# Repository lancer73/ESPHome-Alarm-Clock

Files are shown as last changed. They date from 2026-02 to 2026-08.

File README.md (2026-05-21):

# ESPHome-Alarm-Clock
Alarm clock built in ESPhome with the following features:
- MAX7219 matrix display
- User configurable display behavior for light level and on/off
- One alarm per weekday
- Sensors to let Home Assistant handle the "waking up"
- Automatic fallback to piezo buzzer
- Sensors for automations before and after the alarm time
- Alarm can be triggered from HA for normal and emergency situations
- Switchable led from HA to convey a message or reminder
- Banner message functionality
- Can work without wifi/home assistant. Most important settings are accessible from the alarm clock itself.
- Can be used as a bluetooth proxy for tracking BLE beacons

There are two different versions of the alarm clock. A full version with additional leds and environmental sensors and a light version. 3D print designs are included for both. The normal version has buttons at the top and sensors in the back, the light version has buttons on the front and a ligh sensor on the top.
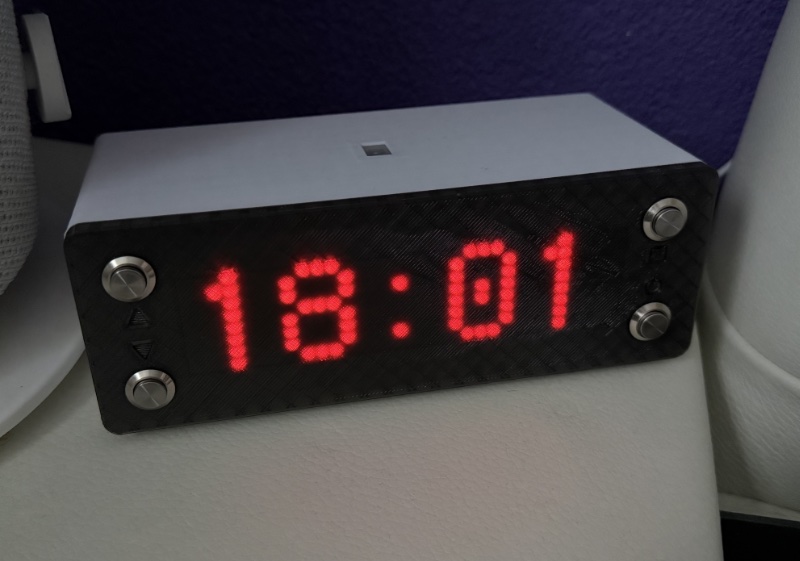
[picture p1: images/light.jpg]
|  | |
|---|---|

## Parts list
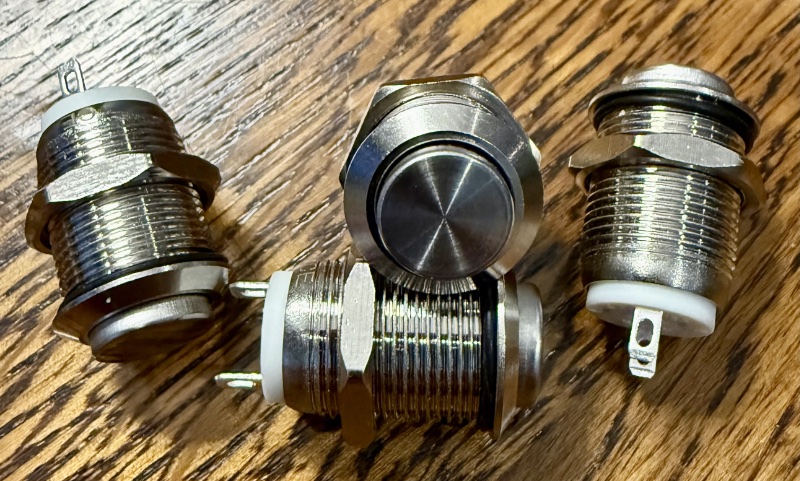
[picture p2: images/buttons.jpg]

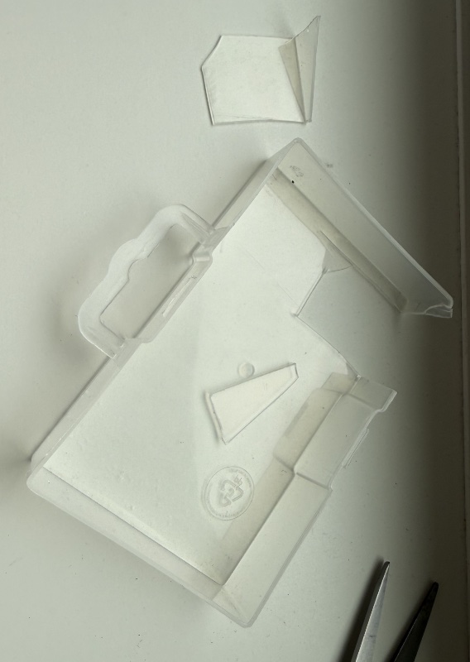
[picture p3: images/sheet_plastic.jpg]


With these parts you can build the "light" version.
- Transparent black filament for 3D print of front
- Colored filament for housing
- Piece of sheet plastic for illumination sensor window (see picture)
- 4x pushbutton (see picture)
- 5x 2k2 resistor
- KY-12 Piezo buzzer
- BH1750 Illumination sensor
- MAX7219 4x8x8 matrix display
- DS1307 real-time clock
- ESP32 DevkitC v4 controller or another ESP controller with enough addressable pins, SPI and I2C bus and an analog-digital converter.
- A piece of electrical tape to cover the led on the controller board (unless you want a "shine in the dark" alarmclock.
- USB cable with USB-A and USB-micro connector
- USB charger

For the full version you need these parts as well:
- CCS811 Gas sensor (TVOC/eCO2 monitoring)
- BMP180 Temperature sensor (for more accurate TVOC metering)
- 3x led in various colors
- 3x resistor in 220 to 600 ohm range (depending on max wanted brightness)

## 3D print
The print files are included in the repository. The normal version comes in three parts, the ligh version in two. I was able to print all parts without supports on a Creality K1C printer. The normal version in the picture was printer with supports, hence the lines below two of the buttons. Print the bodies standing on their backsides.

The other parts can be printed in any color or material. Be aware that if your print in a light color, the led of the controller will shine through. Do not forget to tape off the led.

All parts contain recesses to house the various parts, except for the controller itself. I leave the controller "free floating" in the housing to not push to much stress on the cabling. 

## Assembly
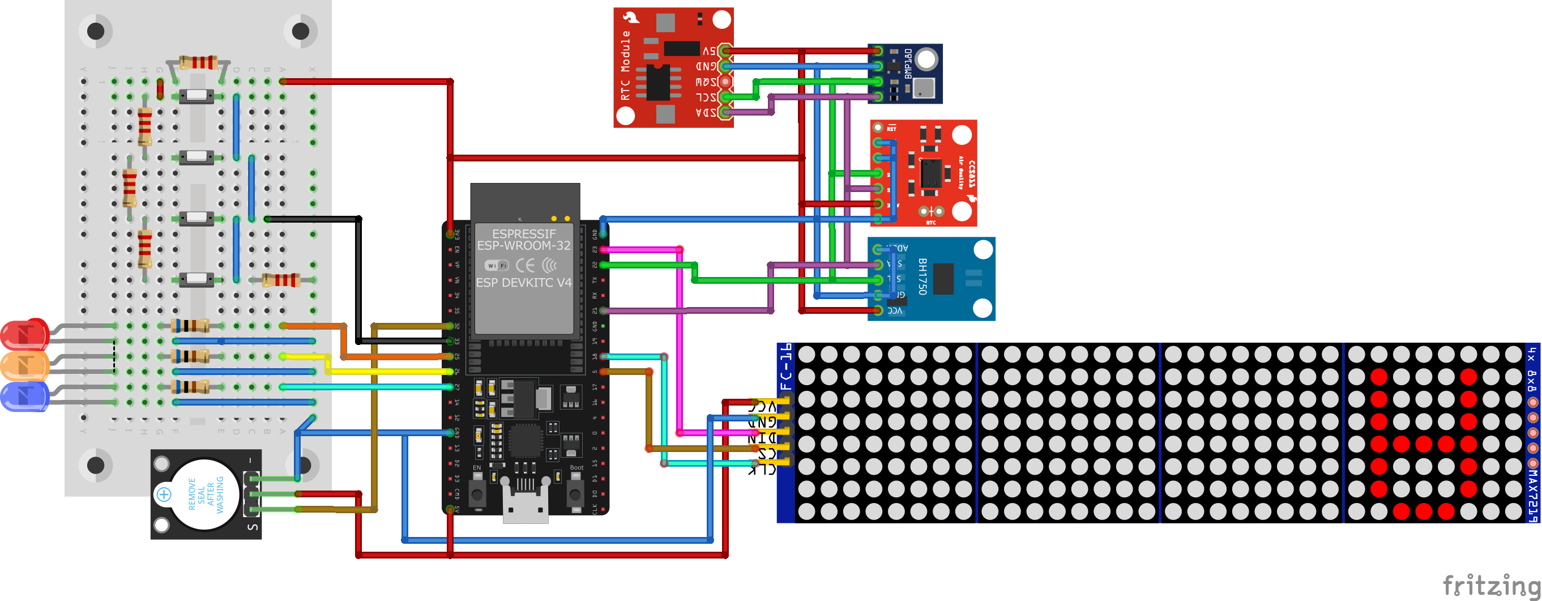
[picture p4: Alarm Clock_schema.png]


The picture above shows the wiring of the alarm clock. Most of it is straightforward. All sensors use the same I2C bus. The led connections are straightforward as well, Use a resistor in the 220 to 600 ohm range, depending on the maximum brightness that is needed from the led. The leds are controlled via the ledc component of ESPhome. The illumination sensor will be used to set the brightness of the leds dynamically.

The buttons are connected in parallel. The resistance will determined by the button that has been pressed. This is measured by an ADC pin of the controller. With no buttons pressed the resistance is indefinite leading to a detected voltage of about 0V. Pressing the top button leads to a total resistant of 4k4 ohms, measured in between the resistors leading to about 1.6V. The lowest button has all 5 resistors in serial connection. The resistor on the red plus line is there to limit the voltage on the ADC pin.

### Pins used
| Pin | Purpose |
|:-----|:---|
| 3v3 | Buttons, BH1750, CCS811, BMP180, DS1307 |
| 5v  | MAX7219 display, KY-12 buzzer |
| GND | Everything leads to GND... |
| GPIO5 | CS connection of MAX7219 |
| GPIO18 | SPI CLK pin of MAX7219 |
| GPIO21 | SDA pin of I2C bus leading to BH1750, CCS811, BMP180, DS1307 |
| GPIO22 | SCL pin of I2C bus leading to BH1750, CCS811, BMP180, DS1307 |
| GPIO23 | SPI MOSI pin for MAX7219 |
| GPIO25 | Red led |
| GPIO26 | Amber led |
| GPIO27 | Blue led |
| GPIO32 | Piezo buzzer, controlled through ledc component to enable tunes & music |
| GPIO33 | Buttons |

### Putting it together
Personnally I like to do everything with Dupont connectors as most builds get taken apart eventually and the parts re-used. When the setup has been tested, the parts can be glued into place. Remeber to put the buttons in first before you solder them as they need to in through a hole. I used hot glue to put everything in place. 

The light alarm clock body has a large hole in the back allowing the micro USB connector to pass (the normal version has a slot). After the cable is in, put the cover in place and hot-glue it in.

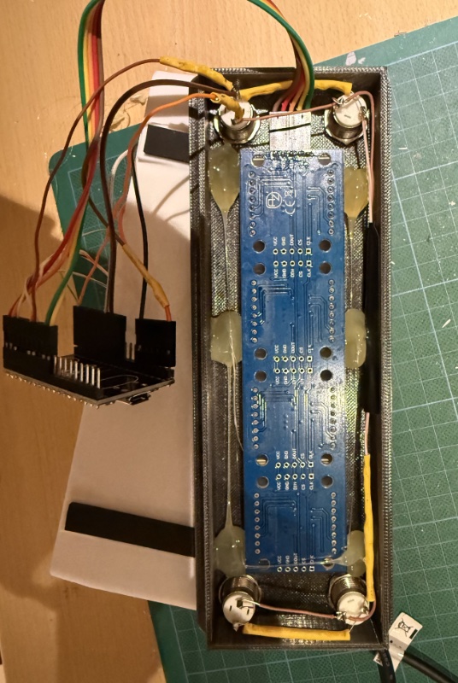
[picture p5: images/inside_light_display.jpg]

The picture on the left shows the MAX7219 display glued in place in the front panel (light version). Make sure the panel fits snugly and that is is completely flat. You will see in the front when it is not. The yellow heat shrink tubing covers the resistors. (this is actually the third one I built. Got tired of crimping on Dupont connectors).

6 dots of hot glue keep everything in place.
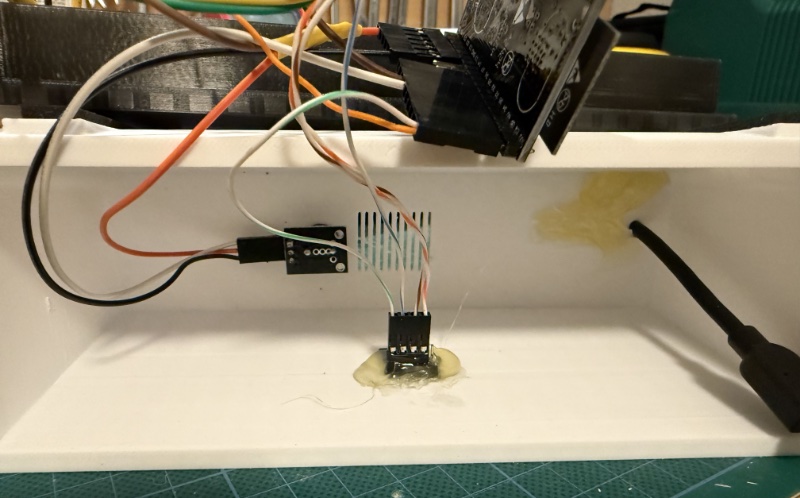
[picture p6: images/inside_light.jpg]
<figure>
Another picture showing the inside of the light version. BH1750 and KY12 are glued in place as is the inset in the connector entry hole in the back. Cut a piece of sheet plastic to size and put it in the recess first, before putting in the BH1750. I used some super glue to gluw the window into place first.

I use a piece of double-sided tape on the battery side to keep the DS1307 in place.

The front display will slide into the housing. It is a tight fit, but fit it does. No glue needed to secure it. The same goes for the back panel of the normal version.

With everything in place you can create the config in ESPHome. Copy the contents of alarm_clock.yaml and adapt where needed. 

Most relevant configurations:
| Substitution | Purpose |
|:---|:---|
| chip_orient and reverse_enable | this allows you to rotate the display if you mount it upside down, or just want to put the alarm clock in an upside down position (attach it to a shelf) |
| hide_button_sensor | change this to false so you can read out the voltage with each button. With these values change the display_min/max (button with the square), onoff_min/max (button with the circle), up_min/max and down_min/max values. Take at least 0.1V of margin above and below the detected value. Make sure button voltage settings do not overlap. |
| baseline | this is the baseline setting for the CCS811 sensor. When first powering up make sure there is an empty string here. Put the alarm clock in a well ventilated position for a few hours and then look at the controller logs to find the baseline of the sensor and copy that value in. |
| weekdays | You can change weekdays to your local language. This sunstitution is just the first 2 letters of all days in the week, starting at Sunday. |

*Do nor forget to set all the passwords and encryption keys in the configuration. Search for text between [] for everything you need to replace.*
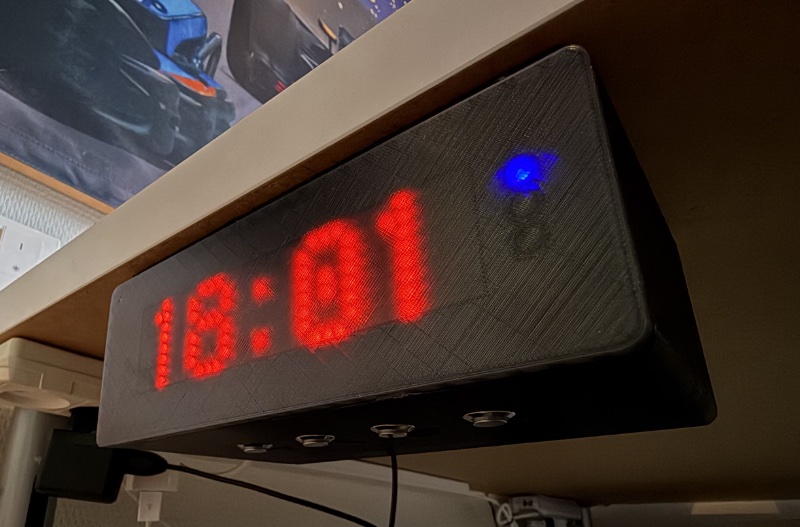
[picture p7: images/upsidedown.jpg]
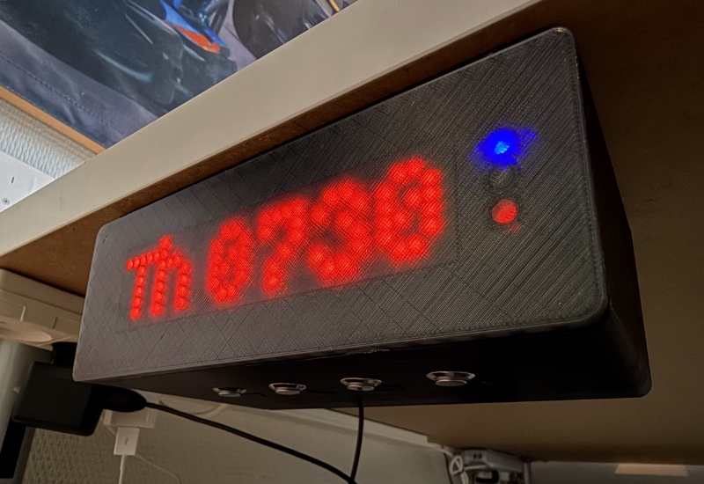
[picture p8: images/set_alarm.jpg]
|  |  |
|---|---|

## Manual
### Manual operation
#### The buttons
| Symbol | Name | Purpose |
|:---|:-----|:---|
| Square | Display | With the display button you can cycle through the pages. Pressing it once will lead to the message and environmental sensors, pressing it twice will lead to the alarm for the next day, pressing it again for the day after etc. If you have no environmental sensors and the message is empty (like after boot), the message is not displayed and the screen skips to the next. Pressing it 8 times will lead back to the time display. The display will revert back to time automatically  (30s timeout by default). If the display is off, this button will turn on the display first. Keep this button pressed to access clock settings. |
| Circle | On/Off | This button either toggles the display on or off when showing time or environment parameters or enable/disable the alarm time or settings shown in the display. By keeping it pressed you can set an alarm time once, meaning the alarm will be disabled for the next week automatically. The red led will show if an alarm is enabled and the amber led will show if it is enabled once. If you have no leds, the status will be shown using the right topmost pixel of the display (red) and the pixel below that (amber).
| Up | Up | When the time or environment parameters are shown, the up button will be forwarded to Home Assistant to control room lights or whatever you choose. When showing an alarm time, it will increase the alarm time by 5 minutes. If you keep the button pressed the time will be counting up in steps of 5 minutes. Up and down are also used to in- or decrease settings.
| Down | Down | Same effect as the up button, but decreasing in time |

#### The display
If an alarm is set within 24 hours the red led or right topmost pixel will light up.

It is possible to turn on the blue led or the right bottemmost pixel from Home Assistant to indicate there is a message. What the message is, is up to you. Could be a signal to put the trash out today, that your favourite GP driver has won in the night race or anything else. I use it to indicate if the alarm clock of a family member has been set.

The amber led will light up of the TVOC reading is above the warning threshold. If you have no leds, it will be the most right 3rd pixel from above.

If the display shows an alarm time, the amber led will indicate if an alarm has been enabled once.

#### When the alarm goes off
When the alarm goes off, the display will invert. Either Home Assistant will arrange the audible alarm e.g. by turning on a remotely controlled speaker, or you can use the built in buzzer. If the connection to Home Assistant has been severed the buzzer will sound anyway. You can use any button to snooze the alarm. The alarm will turn off by itself after 90 minutes by default.

#### When a message is shown
Press any button to dismiss the message. If the message is shown when the alarm goes off, the first press silences the alarm, the second press dismisses the message. I turn my alarm off without looking, that is why a second press is needed.

#### Setting the time manually
Normally the clock will take the time from the Internet. If the Internet is not available, or if you have disabled the wifi you can set the ime manually.

Keep the display button pressed until the network address shows, or "Wifi" crossed out. Press the display button again. The display now shows "St" with the current time. In- or decrease the time with the up/down buttons. The top right pixel or the red led will show up as soon as you change the time, indicating the time has be changed, but not set. The the proper time shows in the display, press "On/Off" to set the time. The time will be set at the press of the button.

Press the display button again to set the year in the "Sy" display. Also here the top right pixel or red led will show up as a sign that the day has changed. Set the configured day by pressing the "On/Off" button. The pixel/led will go out if you do. And the press display again for setting the dat in de "Sd" screen.

#### Other settings
If you press the "Display" button repeatedly you will cycle through the settings. The first setting is the wifi. If the Wifi is enabled and working, it will show an IP address. If the Wifi is off, it wil show "Wifi" crossed out. Toggle the Wifi with the on/off button. If you toggle of the wifi, you will also disable the BLE proxy.
| Code | Setting | Explanation |
|:-----|:---|:---|
| BLE | BLE proxy | The alarm clock can be used as a bluetooth proxy for Home Assistant BLE beacond tracking. Enable/disable by pressing "on/off" |
| St | Set time | Set the time and commit by pressing "on/off" |
| Sy | Set year | Set the current year and commit by pressing "on/off" |
| Sd | Set date | Set the day of the month and the month (ddmm) and commit by pressing "on/off" |
| On | Time to switch the display on | Time at which the display will be switched on automatically. Use the up and down buttons to change the time. The top right pixel or red led will show of the automatic display on/off has been enabled. Use the "On/Off" button to toggle the automatic display setting |
| Of | Time to switch the display off | Analogous to "On" |
| Dt | Display timeout | Number of seconds before the display automatically returns to the time display. When the display is in the off period it will also switch off after this time. The top right pixel or red led will show of the automatic display on/off has been enabled. Use the "On/Off" button to toggle the automatic display setting |
| Db | Display on before alarm | Number of minutes the display will switch on before a set alarm. The top right pixel or red led will show of the automatic display on/off has been enabled. Use the "On/Off" button to toggle the automatic display setting |
| Da | Display off after alarm | Number of minutes the display will switch off after a set alarm in a period when the display should be off. The top right pixel or red led will show of the automatic display on/off has been enabled. Use the "On/Off" button to toggle the automatic display setting |
| Df | Display font | Font for the main (time & message) display. Available are the normal font, a font that mimics a segment display and Star Wars' Aurebesh (2 variants) |
| At | Alarm timeout | Number of minutes after which the alarm should snooze automatically. The top right pixel or red led will show if the alarm buzzer is enabled. Use the "On/Off" button to toggle the buzzer setting. NOTE: If there is no connection to Home Assistant, the buzzer will always sound. |
| *  | Melody | Use up/down to select the wanted melody. Press on/off to play the melody. Melody choices are: Star Wars (Emprire strikes back), Mission Impossible, Mario Kart, Addams Family, Airwolf, James Bond, Swiebertje, Friends and Wake Me Up |
| Ab | Alarm buzzer | Select a random tune for the next alarm of use a single tune always. The top right pixel or red led will show if the alarm buzzer is enabled. Use the "On/Off" button to toggle the buzzer setting. NOTE: If there is no connection to Home Assistant, the buzzer will always sound. |

### Operation from Home Assistant or Web
Home Assistant and the web interface expose many more configurations and parameters. 
#### Alarms
There is an alarm time for every day of the week. The time is valid for that day only. There are two alarm switches for every day. The first will make the alarm go off on that day, the second, when enabled, will disable the alarm for that that after it has sounded. If you turn the once switch on, the alarm switch will be enables as well. If you switch off the alarm switch the once switch will be turned off as well.

There are shortcut buttons to turn off all alarms at once (starting a holiday) or enabling all weekday alarms (at the end of a holody).

#### Display on/off
It is possible to switch the display on and off using the physical buttons. This behavior can be tuned further. The thinking behind this is that some people are distubed hy the alarm display at night, either from the brightness, or because the can see the time. If you can't sleep, seeing the time doesn't necessarity help.

You can set a time at which the display should be turned off and a time when it should be turned on again. This is combined with the "Automatic display on/off" switch, which must be enabled for the set times to have any effect. If the display is off and the time is in the "off" window, the display and in/off buttons will turn on the display and automatically turn it off again after the timeout period.

The following configurations will also influence the display state:
| Setting | Effect |
|:---|:---|
| Display off after alarm | Keeps the display on for a number of minutes after the alarm has been snoozed. (Only valid in the "off window") The display will turned off after set minutes to not disturb other occupants in the bed |
| Display on before alarm | Turns the display on set minutes before the alarm sounds. Useful if you typically wake up before the alarm time. If the display is still of you can close your eyes again, if it is on it might be best to disable the alarm and get up |

#### Other sensors and settings
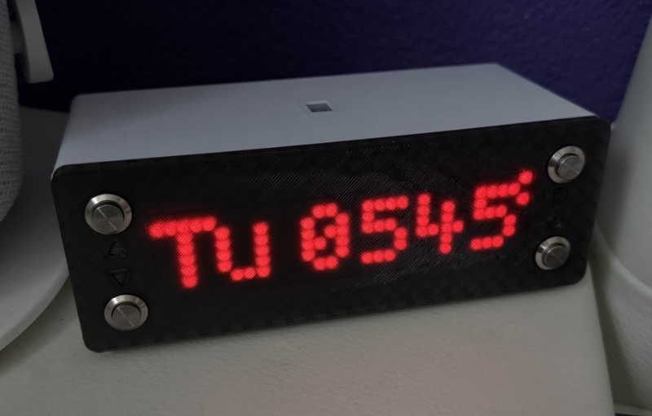
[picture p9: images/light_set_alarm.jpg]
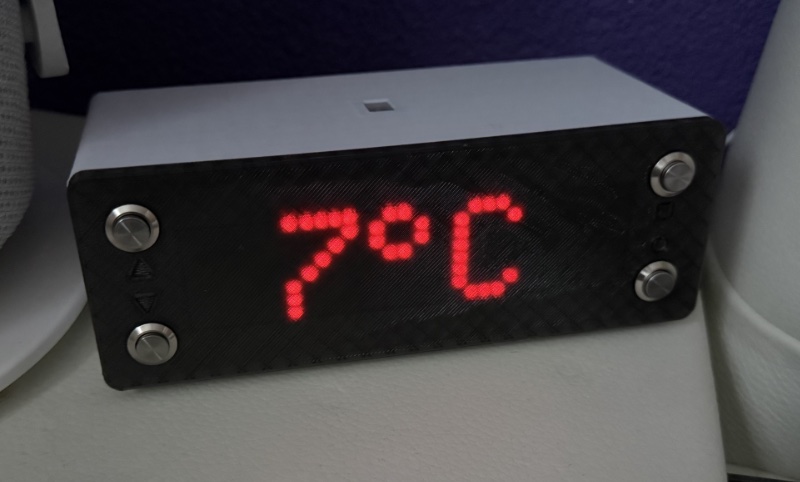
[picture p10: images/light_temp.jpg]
|  |  |
|---|---|
  
| Sensor | Meaning |
|:---|:---|
| Illuminance | Illuminance measured by the sensor. May be used for automatic control of lights for instance. |
| Left button | Binary sensor indicating the state of the down button. This way the press of a button on the alarm clock can turn on the lights. |
| Right button | Binary sensor indicating the state of the up button |
| After last alarm | Number of minutes after the last alarm went off. For automations that need to be kicked off after the alarm time, such as pre-heating the car |
| Alarm countdown | Number of minutes before the alarm. For automations that need to be kicked off before the alarm, such as turning on th ecoffee maker or setting the heating in the bathroom |

| Switch | Meaning |
|:---|:---|
| Alarm | Will turn on when the alarm goes off. To be used in automation to turn on remote speakers or lights when the alarm goes off. Can also be switched on from home assistant. E.g. to synchronise alarms |
| Alert now | Will invert the diplay show "ALARM" and sound a siren using the piezo buzzer. For connecting the alarm clock to a fire alarm, or just to get a teenager out of bed. Alarm can be turned off using a button on the clock. |
| BLE Tracking | Toggles the Bluetooth proxy functionality for tracking BLE beacons |
| Message | Will turn on/off the message/reminder led as a reminder for something, like putting the trash cans out or something else. |
| Buzzer with alarm | When the switch is off, the buzzer will only sound if the connection with Home Assistant has been interrupted. Turn this off if you have an automation to pick up the state of the alarm switch. |
| Buzzer random | Will eelect a random value for the next buzzer. This will actually change the Melody selector |
| Up/Down toggles display | Turn this on if you don't want any automations connected to the up/down buttons. If this switch is on up/down toggles the display on/off when the display shows normal time. |

| Numbers | Meaning |
|:---|:---|
| TVOC warning | Warning level when the TVOC warning led must be turned on. |
| Alarm timeout in minutes | After this time has expired the alarm will be turned off automatically. |
| Display timeout | Number of seconds after the last keypress after which the clock must return to normal time, or turn off again in the "off" window. |
| Maximum brightness at | Number of lux at which the display and leds have maximum brightness |
| Minimum brightness at | Number of lux at which the display has minimum brightness |
| Display font | Font of the time and message display. 0 is the normal font, 1 mimics a segment display, 2 is Aurebesh (Star Wars) and 3 is also Aurebesh, but with the numbers used for currency |
| Melody | Select melody 0 to 8 to play a melody when the alarm sounds (and the buzzer is enabled). Melody choices are: 0 - Star Wars (Emprire strikes back), 1 - Mission Impossible, 2 - Mario Kart, 3 - Addam Family, 4 - Airwolf, 5 - James Bond, 6 - Swiebertje, 7 - Friends and 8 - Wake Me Up  | 

#### Publishing a message for the second display line
You can send a message to the alarm clock. E.g. to display the outside temperature or a message when the alarm clock goes of, or when the display button is pressed once. You can do this via an automation in Home Assistant. To send the outside temperature every 5 minutes the scipt looks something like this:
```
alias: Alarm Clock Message
description: "Send regular updates to the alarm clock"
triggers:
  - trigger: time_pattern
    minutes: /5
conditions: []
actions:
  - action: esphome.[device_name]_publish_message
    metadata: {}
    data:
      message: >-
        {{ states("[your outdoor temp sensor]")|int(default=99)|round(0)
        }}°C
mode: single
```

#### Publishing a banner message
There is a second way to send a message to the alarm clock. Where the first method publishes a message on the second display line (you must press a button to see), this method shows directly, without need for interaction on the alarm clock. The user can dismiss the message on the alarm clock by pressing a button. If the message is published before the alarm goes off, the message will survive the silencing of the alarm.

You can, for instance, define an input_text helper in Home Assistant to display a message on the alarm clock. After definition of the helper, create the following automation:
```
alias: Set banner message in alarm clock
description: ""
triggers:
  - trigger: state
    entity_id:
      - input_text.[my_helper]
conditions:
  - condition: template
    value_template: "{{ (as_timestamp(now()) - as_timestamp(states(\"sensor.uptime\"))) > 60 }}"
actions:
  - action: esphome.[device_name]_banner_message
    data:
      message: "{{ states('input_text.[my_helper]') }}"
mode: single
```

#### Font showcase
| Font | Image|
|:-----|-----:|
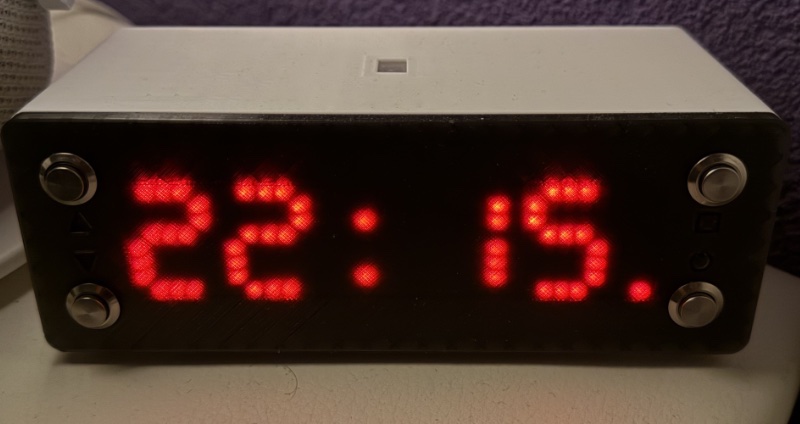
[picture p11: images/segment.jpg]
| Segment |  |
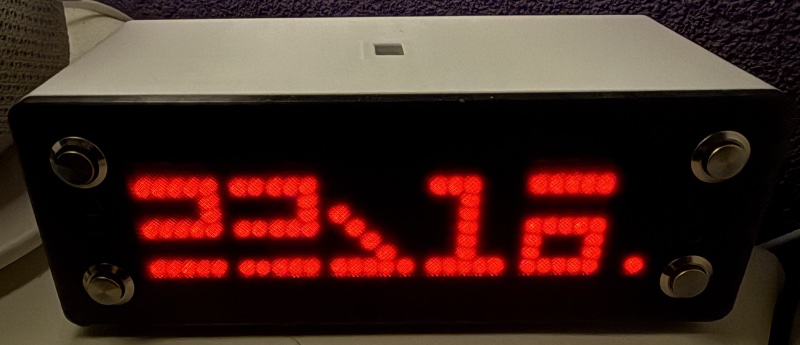
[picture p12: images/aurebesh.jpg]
| Aurebesh |  |
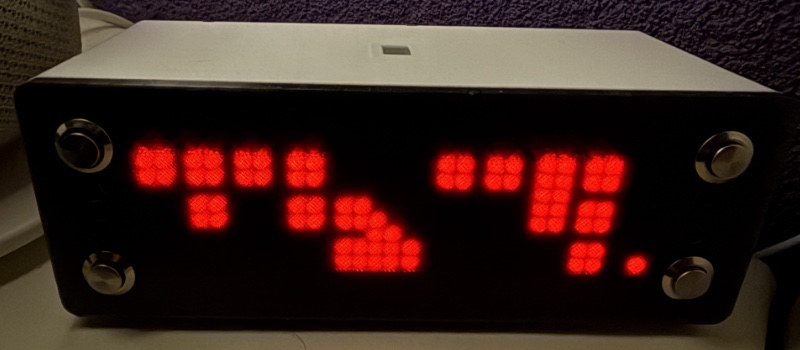
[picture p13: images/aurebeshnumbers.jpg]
| Aurebesh numbers |  |

## Home Assistant dashboards
I also created some dashboards to control the alarm clock. I have one dashboard with all the alarm clocks and the alarm for the next day and a dedicated dashboard per alarm clock for all the settings. This requires the Mushroom addon cards.

### The short insert into an overview page
```
type: grid
cards:
  - type: heading
    heading: Wekkers
    heading_style: title
    icon: mdi:alarm
  - type: heading
    icon: mdi:face-man-outline
    heading_style: subtitle
    heading: Alarm Clock John
    badges: []
  - type: tile
    entity: time.[device_name]_monday_alarm
    name: Maandag
    vertical: false
    features_position: bottom
    grid_options:
      columns: 6
      rows: 1
    visibility:
      - condition: time
        after: "00:00:00"
        before: "23:59:00"
        weekdays:
          - sun
  - type: custom:mushroom-entity-card
    entity: switch.[device_name]_monday_alarm
    primary_info: none
    secondary_info: none
    hold_action:
      action: more-info
    tap_action:
      action: toggle
    visibility:
      - condition: time
        after: "00:00:00"
        before: "23:59:00"
        weekdays:
          - sun
  - type: custom:mushroom-entity-card
    entity: switch.[device_name]_monday_alarm_once
    primary_info: none
    secondary_info: none
    tap_action:
      action: toggle
    hold_action:
      action: more-info
    double_tap_action:
      action: toggle
    visibility:
      - condition: time
        after: "00:00:00"
        before: "23:59:00"
        weekdays:
          - sun
  - type: tile
    entity: time.[device_name]_tuesday_alarm
    name: Dinsdag
    vertical: false
    features_position: bottom
    grid_options:
      columns: 6
      rows: 1
    visibility:
      - condition: time
        after: "00:00:00"
        before: "23:59:00"
        weekdays:
          - mon
  - type: custom:mushroom-entity-card
    entity: switch.[device_name]_tuesday_alarm
    primary_info: none
    secondary_info: none
    hold_action:
      action: more-info
    tap_action:
      action: toggle
    visibility:
      - condition: time
        after: "00:00:00"
        before: "23:59:00"
        weekdays:
          - mon
  - type: custom:mushroom-entity-card
    entity: switch.[device_name]_tuesday_alarm_once
    primary_info: none
    secondary_info: none
    tap_action:
      action: toggle
    hold_action:
      action: more-info
    double_tap_action:
      action: toggle
    visibility:
      - condition: time
        after: "00:00:00"
        before: "23:59:00"
        weekdays:
          - mon
  - type: tile
    entity: time.[device_name]_wednesday_alarm
    name: Woensdag
    vertical: false
    features_position: bottom
    grid_options:
      columns: 6
      rows: 1
    visibility:
      - condition: time
        after: "00:00:00"
        before: "23:59:00"
        weekdays:
          - tue
  - type: custom:mushroom-entity-card
    entity: switch.[device_name]_wednesday_alarm
    primary_info: none
    secondary_info: none
    hold_action:
      action: more-info
    tap_action:
      action: toggle
    visibility:
      - condition: time
        after: "00:00:00"
        before: "23:59:00"
        weekdays:
          - tue
  - type: custom:mushroom-entity-card
    entity: switch.[device_name]_wednesday_alarm_once
    primary_info: none
    secondary_info: none
    tap_action:
      action: toggle
    hold_action:
      action: more-info
    double_tap_action:
      action: toggle
    visibility:
      - condition: time
        after: "00:00:00"
        before: "23:59:00"
        weekdays:
          - tue
  - type: tile
    entity: time.[device_name]_thursday_alarm
    name: Donderdag
    vertical: false
    features_position: bottom
    grid_options:
      columns: 6
      rows: 1
    visibility:
      - condition: time
        after: "00:00:00"
        before: "23:59:00"
        weekdays:
          - wed
  - type: custom:mushroom-entity-card
    entity: switch.[device_name]_thursday_alarm
    primary_info: none
    secondary_info: none
    hold_action:
      action: more-info
    tap_action:
      action: toggle
    visibility:
      - condition: time
        after: "00:00:00"
        before: "23:59:00"
        weekdays:
          - wed
  - type: custom:mushroom-entity-card
    entity: switch.[device_name]_thursday_alarm_once
    primary_info: none
    secondary_info: none
    tap_action:
      action: toggle
    hold_action:
      action: more-info
    double_tap_action:
      action: toggle
    visibility:
      - condition: time
        after: "00:00:00"
        before: "23:59:00"
        weekdays:
          - wed
  - type: tile
    entity: time.[device_name]l_friday_alarm
    name: Vrijdag
    vertical: false
    features_position: bottom
    grid_options:
      columns: 6
      rows: 1
    visibility:
      - condition: time
        after: "00:00:00"
        before: "23:59:00"
        weekdays:
          - thu
  - type: custom:mushroom-entity-card
    entity: switch.[device_name]_friday_alarm
    primary_info: none
    secondary_info: none
    hold_action:
      action: more-info
    tap_action:
      action: toggle
    visibility:
      - condition: time
        after: "00:00:00"
        before: "23:59:00"
        weekdays:
          - thu
  - type: custom:mushroom-entity-card
    entity: switch.[device_name]_friday_alarm_once
    primary_info: none
    secondary_info: none
    tap_action:
      action: toggle
    hold_action:
      action: more-info
    double_tap_action:
      action: toggle
    visibility:
      - condition: time
        after: "00:00:00"
        before: "23:59:00"
        weekdays:
          - thu
  - type: tile
    entity: time.[device_name]_saturday_alarm
    name: Zaterdag
    vertical: false
    features_position: bottom
    grid_options:
      columns: 6
      rows: 1
    visibility:
      - condition: time
        after: "00:00:00"
        before: "23:59:00"
        weekdays:
          - fri
  - type: custom:mushroom-entity-card
    entity: switch.[device_name]_saturday_alarm
    primary_info: none
    secondary_info: none
    hold_action:
      action: more-info
    tap_action:
      action: toggle
    visibility:
      - condition: time
        after: "00:00:00"
        before: "23:59:00"
        weekdays:
          - fri
  - type: custom:mushroom-entity-card
    entity: switch.[device_name]_saturday_alarm_once
    primary_info: none
    secondary_info: none
    tap_action:
      action: toggle
    hold_action:
      action: more-info
    double_tap_action:
      action: toggle
    visibility:
      - condition: time
        after: "00:00:00"
        before: "23:59:00"
        weekdays:
          - fri
  - type: tile
    entity: time.[device_name]_sunday_alarm
    name: Zondag
    vertical: false
    features_position: bottom
    grid_options:
      columns: 6
      rows: 1
    visibility:
      - condition: time
        after: "00:00:00"
        before: "23:59:00"
        weekdays:
          - sat
  - type: custom:mushroom-entity-card
    entity: switch.[device_name]_sunday_alarm
    primary_info: none
    secondary_info: none
    hold_action:
      action: more-info
    tap_action:
      action: toggle
    visibility:
      - condition: time
        after: "00:00:00"
        before: "23:59:00"
        weekdays:
          - sat
  - type: custom:mushroom-entity-card
    entity: switch.[device_name]_sunday_alarm_once
    primary_info: none
    secondary_info: none
    tap_action:
      action: toggle
    hold_action:
      action: more-info
    double_tap_action:
      action: toggle
    visibility:
      - condition: time
        after: "00:00:00"
        before: "23:59:00"
        weekdays:
          - sat
  - type: tile
    grid_options:
      columns: full
    entity: binary_sensor.[device_name]_status
    name: Alle wektijden
    icon: mdi:clock-digital
    color: primary
    hide_state: true
    vertical: false
    tap_action:
      action: navigate
      navigation_path: /lovelace/[device_name]
    icon_tap_action:
      action: navigate
      navigation_path: /lovelace/[device_name]
```
### A subview for all alarm clock settings
```
type: sections
max_columns: 2
title: Alarm clock
path: [device_name]
icon: mdi:alarm
sections:
  - type: grid
    cards:
      - type: heading
        icon: mdi:face-man-outline
        heading_style: title
        heading: Alarm Clock John
        badges:
          - type: entity
            show_state: true
            show_icon: true
            visibility:
              - condition: numeric_state
                entity: sensor.[device_name]_alarm_countdown
                below: 2880
            entity: sensor.[device_name]_alarm_countdown
            name: Volgende over
            state_content:
              - name
              - state
            tap_action:
              action: more-info
      - type: tile
        entity: button.[device_name]_toggle_all_alarms_off
        name: Alles uit
        hide_state: true
        vertical: false
        features_position: bottom
      - type: tile
        entity: button.[device_name]_toggle_weekday_alarms_on
        name: Weekdagen
        hide_state: true
        vertical: false
        features_position: bottom
      - type: tile
        entity: time.[device_name]_monday_alarm
        name: Maandag
        vertical: false
        features_position: bottom
        grid_options:
          columns: 6
          rows: 1
      - type: custom:mushroom-entity-card
        entity: switch.[device_name]_monday_alarm
        primary_info: none
        secondary_info: none
        hold_action:
          action: more-info
        tap_action:
          action: toggle
      - type: custom:mushroom-entity-card
        entity: switch.[device_name]_monday_alarm_once
        primary_info: none
        secondary_info: none
        tap_action:
          action: toggle
        hold_action:
          action: more-info
        double_tap_action:
          action: toggle
      - type: tile
        entity: time.[device_name]_tuesday_alarm
        name: Dinsdag
        vertical: false
        features_position: bottom
        grid_options:
          columns: 6
          rows: 1
      - type: custom:mushroom-entity-card
        entity: switch.[device_name]_tuesday_alarm
        primary_info: none
        secondary_info: none
        hold_action:
          action: more-info
        tap_action:
          action: toggle
      - type: custom:mushroom-entity-card
        entity: switch.[device_name]_tuesday_alarm_once
        primary_info: none
        secondary_info: none
        tap_action:
          action: toggle
        hold_action:
          action: more-info
        double_tap_action:
          action: toggle
      - type: tile
        entity: time.[device_name]_wednesday_alarm
        name: Woensdag
        vertical: false
        features_position: bottom
        grid_options:
          columns: 6
          rows: 1
      - type: custom:mushroom-entity-card
        entity: switch.[device_name]_wednesday_alarm
        primary_info: none
        secondary_info: none
        hold_action:
          action: more-info
        tap_action:
          action: toggle
      - type: custom:mushroom-entity-card
        entity: switch.[device_name]_wednesday_alarm_once
        primary_info: none
        secondary_info: none
        tap_action:
          action: toggle
        hold_action:
          action: more-info
        double_tap_action:
          action: toggle
      - type: tile
        entity: time.[device_name]_thursday_alarm
        name: Donderdag
        vertical: false
        features_position: bottom
        grid_options:
          columns: 6
          rows: 1
      - type: custom:mushroom-entity-card
        entity: switch.[device_name]_thursday_alarm
        primary_info: none
        secondary_info: none
        hold_action:
          action: more-info
        tap_action:
          action: toggle
      - type: custom:mushroom-entity-card
        entity: switch.[device_name]_thursday_alarm_once
        primary_info: none
        secondary_info: none
        tap_action:
          action: toggle
        hold_action:
          action: more-info
        double_tap_action:
          action: toggle
      - type: tile
        entity: time.[device_name]_friday_alarm
        name: Vrijdag
        vertical: false
        features_position: bottom
        grid_options:
          columns: 6
          rows: 1
      - type: custom:mushroom-entity-card
        entity: switch.[device_name]_friday_alarm
        primary_info: none
        secondary_info: none
        hold_action:
          action: more-info
        tap_action:
          action: toggle
      - type: custom:mushroom-entity-card
        entity: switch.[device_name]_friday_alarm_once
        primary_info: none
        secondary_info: none
        tap_action:
          action: toggle
        hold_action:
          action: more-info
        double_tap_action:
          action: toggle
      - type: tile
        entity: time.[device_name]_saturday_alarm
        name: Zaterdag
        vertical: false
        features_position: bottom
        grid_options:
          columns: 6
          rows: 1
      - type: custom:mushroom-entity-card
        entity: switch.[device_name]_saturday_alarm
        primary_info: none
        secondary_info: none
        hold_action:
          action: more-info
        tap_action:
          action: toggle
      - type: custom:mushroom-entity-card
        entity: switch.[device_name]_saturday_alarm_once
        primary_info: none
        secondary_info: none
        tap_action:
          action: toggle
        hold_action:
          action: more-info
        double_tap_action:
          action: toggle
      - type: tile
        entity: time.[device_name]_sunday_alarm
        name: Zondag
        vertical: false
        features_position: bottom
        grid_options:
          columns: 6
          rows: 1
      - type: custom:mushroom-entity-card
        entity: switch.[device_name]_sunday_alarm
        primary_info: none
        secondary_info: none
        hold_action:
          action: more-info
        tap_action:
          action: toggle
      - type: custom:mushroom-entity-card
        entity: switch.[device_name]_sunday_alarm_once
        primary_info: none
        secondary_info: none
        tap_action:
          action: toggle
        hold_action:
          action: more-info
        double_tap_action:
          action: toggle
  - type: grid
    cards:
      - type: heading
        heading: Settings Alarm Clock
        heading_style: title
      - type: entities
        entities:
          - entity: switch.[device_name]_display_aan_uit
          - entity: switch.[device_name]_automatic_display_on_off
          - entity: time.[device_name]_display_on_at
          - entity: time.[device_name]_display_off_at
          - entity: number.[device_name]_display_on_before_alarm
          - entity: number.[device_name]_display_off_after_alarm
          - entity: number.[device_name]_display_timeout_in_seconds
        show_header_toggle: false
      - type: tile
        entity: input_text.[device_name]_bericht
        vertical: false
        features_position: bottom
        grid_options:
          columns: full
subview: true
cards: []
```

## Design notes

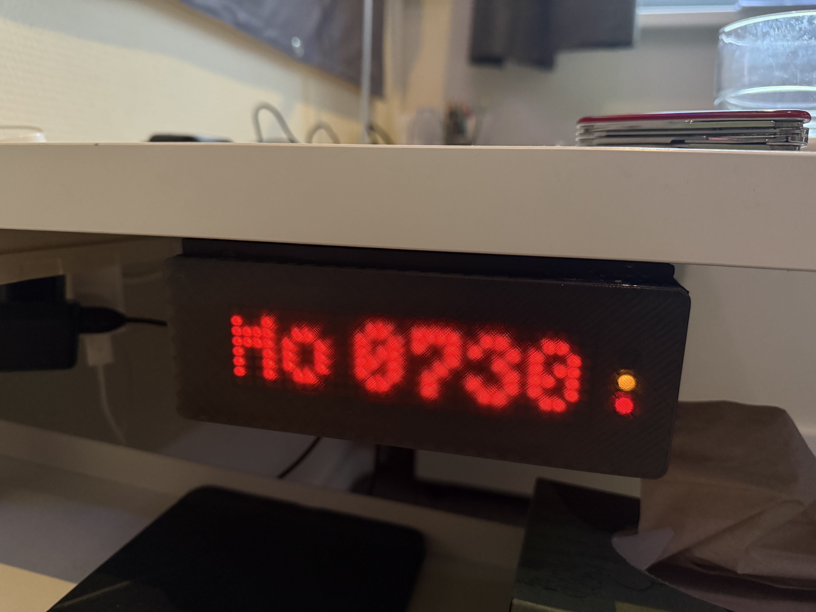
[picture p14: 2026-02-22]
images/alarm_clock_showing_alarm_once.jpeg

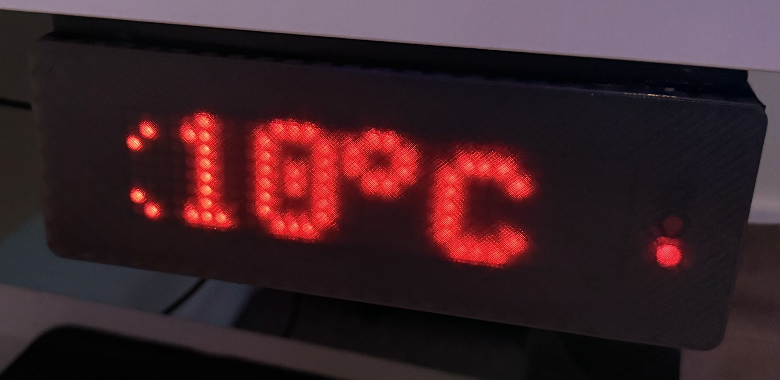
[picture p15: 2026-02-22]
images/alarm_clock_showing_temp.jpeg

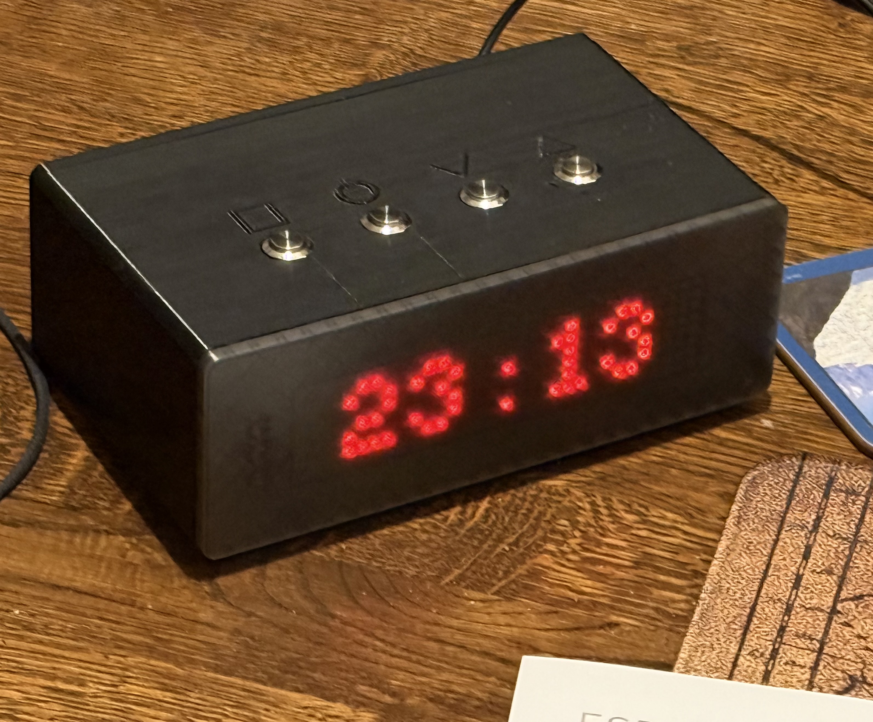
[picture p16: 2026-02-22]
images/alarm_clock_spleen_font.jpeg

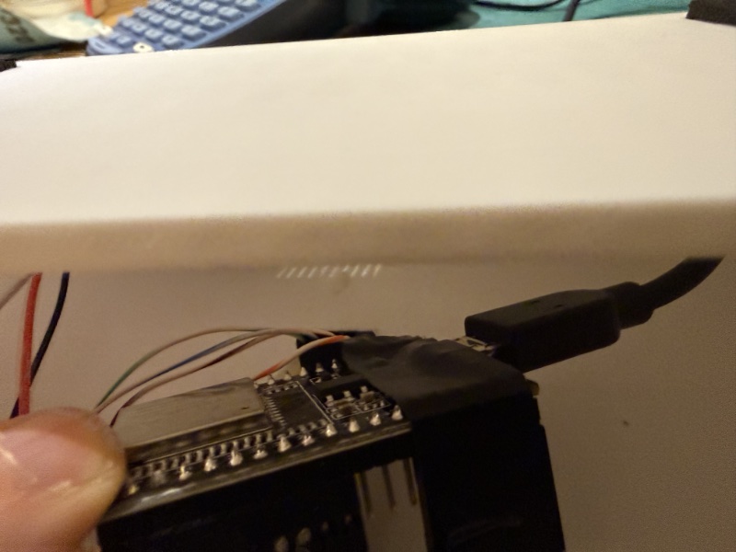
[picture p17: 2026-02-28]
images/tapeoffled.jpg

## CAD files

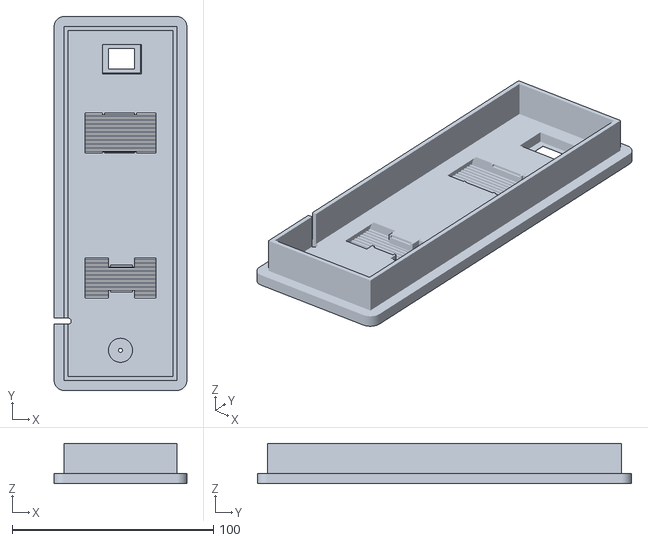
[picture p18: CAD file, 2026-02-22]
Alarm Clock Rear.stl
66.0 x 186.0 x 20.0

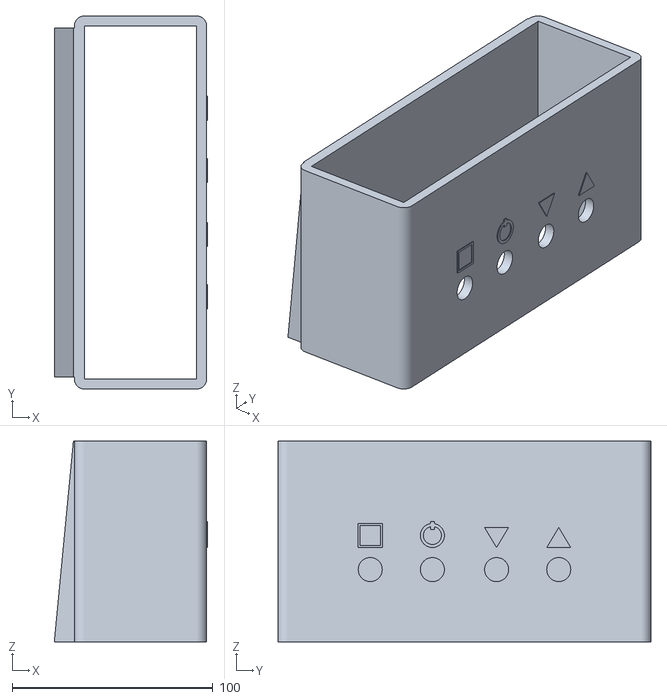
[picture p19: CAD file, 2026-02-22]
Alarm Clock Body.stl
76.5 x 186.0 x 100.0

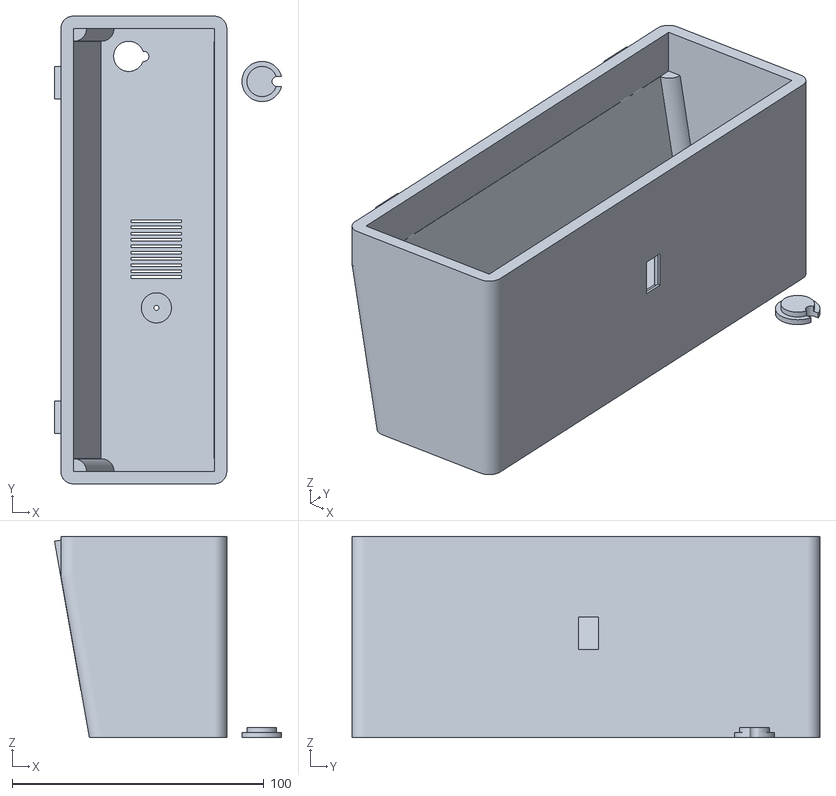
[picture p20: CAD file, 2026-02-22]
Alarm Clock Body Light.stl
90.3 x 186.0 x 80.0

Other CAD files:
Alarm Clock Front.stl
Alarm Clock Front Light.stl

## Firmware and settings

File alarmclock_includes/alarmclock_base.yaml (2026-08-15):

# Enable the wifi if such is configured
esphome:
  on_boot:
    - priority: -10
      then:
        - delay: 2s
        - if:
            condition:
              lambda: 'return id(ble_tracking_enabled);'
            then:
              - lambda: |-
                   id(bt_proxy).set_active(true);
              - esp32_ble_tracker.start_scan:
                  id: ble_tracker
                  continuous: true
            else:
              - esp32_ble_tracker.stop_scan:
                  id: ble_tracker
              - lambda: |-
                   id(bt_proxy).set_active(false);
    - priority: 250
      then: 
        - if:
            condition:
              lambda: 'return id(wifi_enabled);'
            then:
              wifi.enable:
    - priority: 800
      then:
        - ds1307.read_time:
        - text_sensor.template.publish:
            id: message_line
            state: ""

api:
  services:
  - service: publish_message
    variables:
      message: string
    then:
      - text_sensor.template.publish:
          id: message_line
          state: !lambda 'return message;'
  - service: banner_message
    variables:
      message: string
    then:
      - text_sensor.template.publish:
          id: show_message
          state: !lambda 'return message;'
          
# Enable the webserver and create groups for the dashboard
# The webserver is for control purposes. No OTA and no LOG
# Run fully local.
web_server:
  port: 80
  version: 3
  local: True
  sorting_groups:
    - id: alarm_time
      name: "Alarm times"
      sorting_weight: 10
    - id: alarm_control
      name: "Control"
      sorting_weight: 20
    - id: alarm_environment
      name: "Environment"
      sorting_weight: 30
    - id: alarm_config
      name: "Alarm configuration"
      sorting_weight: 40
    - id: alarm_diag
      name: "Diagnostics"
      sorting_weight: 50

globals:
  # Which content to show
  - id: disp_line
    type: int
    restore_value: no
    initial_value: "0"
  # To set the brightness of the MAX7219. Needs to be between 0 and 15
  - id: disp_brightness
    type: int
    restore_value: no
    initial_value: "0"
  # Automatic turning on and off of the display
  - id: display_onoff_hour
    type: int[2]
    restore_value: yes
    initial_value: '{7,23}'
  - id: display_onoff_minute
    type: int[2]
    restore_value: yes
    initial_value: '{0,0}'
  # Alarm times. One for every day of the week
  # The hour the alarm needs to sound
  - id: alarm_hour
    type: int[7]
    restore_value: yes
    initial_value: '{7,7,7,7,7,7,7}'
  # The Minute the alarm needs to sound
  - id: alarm_minute
    type: int[7]
    restore_value: yes 
    initial_value: '{0,0,0,0,0,0,0}'
  # Alarm enable/disable
  - id: alarm_on
    type: bool[7]
    restore_value: yes
    initial_value: '{false,false,false,false,false,false,false}'
  # If this is enabled the alarm will sound and then disable itself
  - id: alarm_on_once
    type: bool[7]
    restore_value: yes
    initial_value: '{false,false,false,false,false,false,false}'
  # If this counter reaches 0 the display switches back to line 0. Set in seconds
  - id: disp_timeout
    type: int
    initial_value: "0"
    restore_value: no
  # Wether the left button (down) is pressed
  - id: btn_left
    type: bool
    restore_value: no
    initial_value: "false"
  # Wether the right button (up) is pressed
  - id: btn_right
    type: bool
    restore_value: no
    initial_value: "false"
  # Time in minutes the alarm is allowed to sound.
  - id: alarm_timeout
    type: int
    initial_value: "1420"
    restore_value: no
  # Countdown timer in minutes for the next alarm
  - id: next_alarm
    type: int
    initial_value: "2880"
    restore_value: no
  # We are in the time of that that the display should be off
  - id: offperiod
    type: bool
    initial_value: "false"
    restore_value: no
  # State of the message indicator (blue led or right bottom pixel
  - id: message_state
    type: bool
    restore_value: no
    initial_value: "false"
  # Register needed for setting the hour
  - id: current_hour
    type: int
    initial_value: "0"
    restore_value: no
  # Register for setting the minute
  - id: current_minute
    type: int
    initial_value: "0"
    restore_value: no
  # Register for setting the year
  - id: current_year
    type: int
    initial_value: "0"
    restore_value: no
  # Register for setting the month
  - id: current_month
    type: int
    initial_value: "0"
    restore_value: no
  # Register for setting the day
  - id: current_day
    type: int
    initial_value: "0"
    restore_value: no
  # Register for setting the days per month. Feb-28 is not worth the trouble
  - id: max_days
    type: int[12]
    initial_value: '{31,27,31,30,31,30,31,31,30,31,30,31}'
    restore_value: no
  # Register for detecting if the time setting has changed
  - id: time_changed
    type: bool
    initial_value: "false"
    restore_value: no
  # If wifi must be enabled
  - id: wifi_enabled
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

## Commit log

2026-02-22 Add files via upload
    Initial commit. README still todo
    [Alarm Clock Body Light.stl, Alarm Clock Body.stl, Alarm Clock Front Light.stl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]
2026-02-22 Update alarm_clock.yaml
    Set led transition length
2026-02-26 Updates switches
2026-03-01 Add message functionality
    Add message functionality for non-led version. Use lower right hand dot.
2026-03-01 Enhance README with alarm clock details and instructions
    Updated README.md to include details about alarm clock versions, parts list, and 3D printing instructions.
2026-03-01 Enhance README with assembly and configuration details
    Updated the README to include additional details about the ESP32 controller and clarified assembly instructions, wiring, and configuration settings.
2026-03-01 Enhance README with manual operation details
    Added detailed manual operation instructions and button functionalities for the alarm clock.
2026-03-01 Fix font file name and adjust alarm time display format
    [alarmclock_base.yaml]
2026-03-07 Add led control for configuration settings
2026-03-07 Add settings screens, incorporate DS1307
    Clock can now work without Wifi. Wifi can even be turned off. Most important settings are accessible on the clock display. Keep the display button pressed to enter the settings screen.
    Alarm Once action has changed from double_press to keep pressed.
2026-03-07 Revise button descriptions and add manual time setting
    Updated button functionalities and added manual time setting instructions.
2026-03-07 Reset display timeout on long press display
    [alarmclock_base.yaml]
2026-03-07 Update README with DS1307 and pin changes
    Added DS1307 real-time clock to components list and updated pin assignments in the README.
2026-03-07 Fix image link for alarm clock assembly diagram
    Updated the image link for the alarm clock wiring diagram in the assembly section.
2026-03-19 Added functionality
    - Configurable melodies
    - Faster update of display brightness
    - Removal of outdoor sensor in favor of a generic text sensor to add messages to the display
2026-03-19 Delete alarmclock_base.yaml
    Wrong dir
    [alarmclock_base.yaml]
2026-03-19 Update README.md
    Added functionality
    - Removal of outdoor temp sensor in favor of generic text sensor
    - Selectable melodies
2026-03-24 Another font and random buzzer
    Add a switch to randomly select a new tune for the next alarm
    A variant of the Aurebesh font which is based on normal numbers
    [alarmclock_base.yaml]
2026-03-28 Fix font display in all eventualities
    [alarmclock_base.yaml]
2026-04-25 Fix conditions and calculations in alarm clock logic
    [alarmclock_base.yaml]
2026-04-26 Add conditional amber LED control based on HAS_TVOC
    Led stays on after alarm config otherwise
2026-05-21 BLE tracking
    Added bluetooth proxy for BLE tracking. Added switch in HA and on clock configuration.
2026-08-15 Update alarm clock version to 1.3.1
    Switch authentication to "digest" explicitly.
2026-08-15 Add timezone configuration to ds1307 platform
    Set timezone explicitly. Update to 2026.7.4 exposed this bug; clock started running at UTC.
    [alarmclock_base.yaml]
